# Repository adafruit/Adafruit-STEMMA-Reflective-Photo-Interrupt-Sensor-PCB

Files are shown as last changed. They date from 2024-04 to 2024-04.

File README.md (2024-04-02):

## Adafruit STEMMA Reflective Photo Interrupt Sensor - TCRT1000 PCB

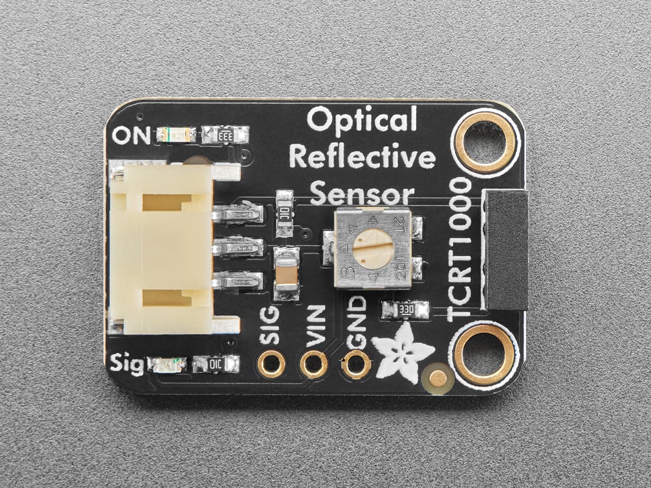
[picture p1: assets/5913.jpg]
<a href="http://www.adafruit.com/products/5913"><br/>
Click here to purchase one from the Adafruit shop</a>

PCB files for the Adafruit STEMMA Reflective Photo Interrupt Sensor - TCRT1000. 

Format is EagleCAD schematic and board layout
* https://www.adafruit.com/product/5913

### Description

An optical reflective sensor is a composite electronic device with two elements - an IR LED and an IR photo-transistor. The IR LED blasts light, and when something bounces the light back to the photo-transistor, the transistor turns on and the amount of current flowing through it increases. This makes the sensor great at detecting when something is in front of the sensor: when nothing is there the IR light never gets reflected back and the transistor stays off.

We have two versions of this sensor that are 'breadboard' friendly, the ITR20001 and a chunky all-in-one Infrared Reflective Sensor, but both are tough to mount, and require wiring up with resistors to get working. To make usage super fast and no-soldering-or-breadboarding-required, the Adafruit STEMMA Reflective Photo Interrupt Sensor is ready to go out of the box.

Power it with 3 to 5V DC and read the signal off the output pin to quickly detect reflective surfaces. A green LED tells you that the board is powered,  and a red LED will light up to let you know when the phototransistor is activated. (Both LEDs can be disabled)

Onboard we have a TCRT1000 right-angle sensor module. A potentiometer allows adjustment of how bright the IR emitter is, turn it all the way down for about 1mA, turn it all the way up for about 100mA. Then the receiving phototransistor is biased with a 10K pullup. When no IR light is detected, the output signal pin is high. When IR is bounced back, the voltage will drop down towards 0V.

This board has a simple plug-and-play JST PH (2mm pitch) input connector for solderless use. For use with a CircuitPlayground or micro:bit, this JST to alligator-clip cable works best. Red is power, ground is black and signal is white. For use with a breadboard, try this JST to male/plug-header. (We also have a socket-header cable if you want)

### License

Adafruit invests time and resources providing this open source design, please support Adafruit and open-source hardware by purchasing products from [Adafruit](https://www.adafruit.com)!

Designed by Limor Fried/Ladyada for Adafruit Industries.

Creative Commons Attribution/Share-Alike, all text above must be included in any redistribution. 
See license.txt for additional details.

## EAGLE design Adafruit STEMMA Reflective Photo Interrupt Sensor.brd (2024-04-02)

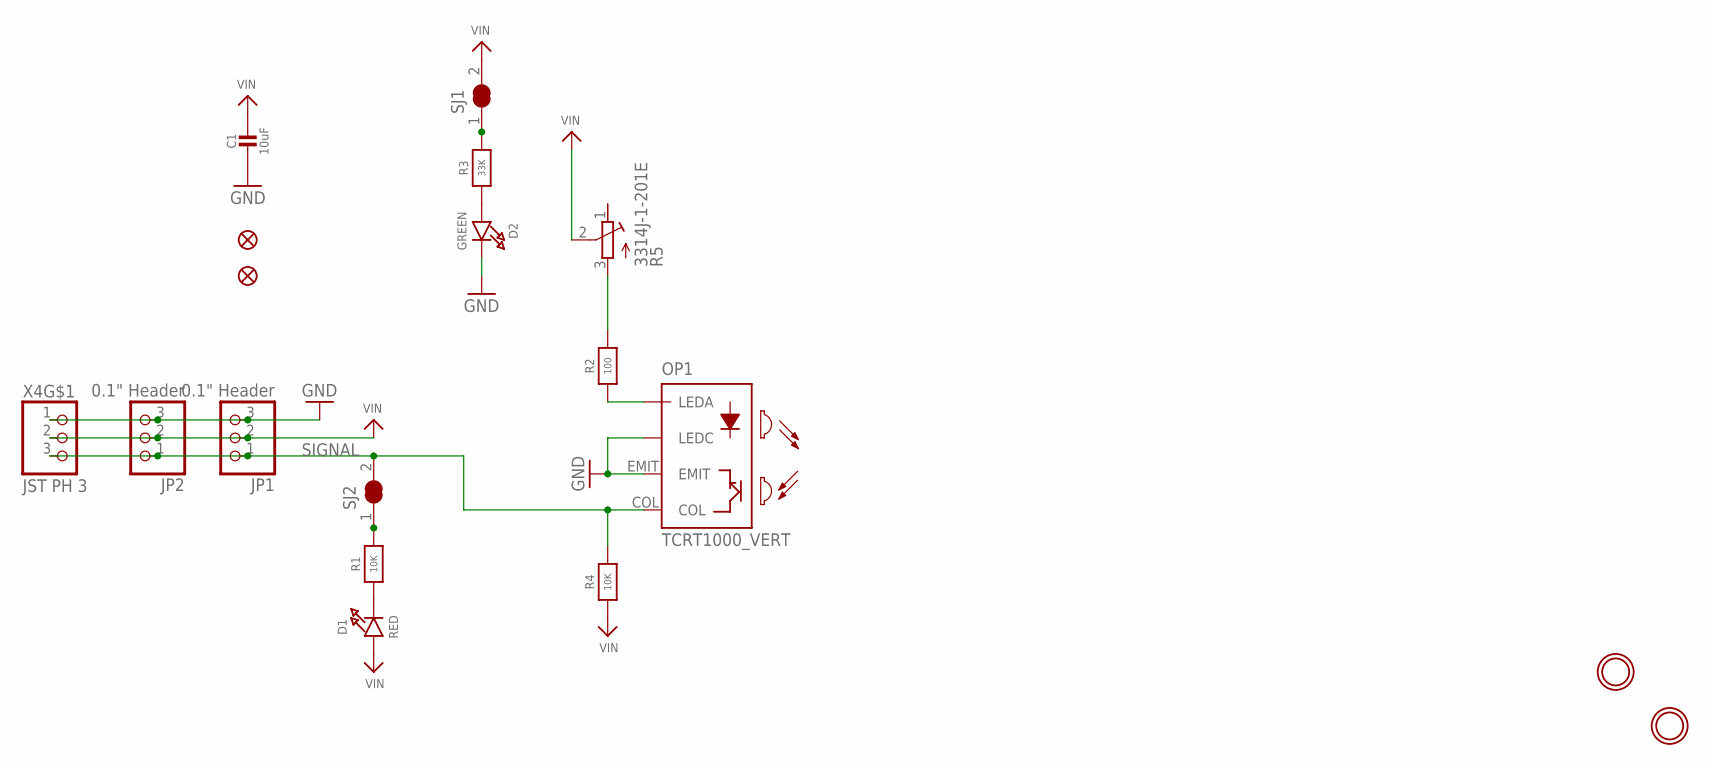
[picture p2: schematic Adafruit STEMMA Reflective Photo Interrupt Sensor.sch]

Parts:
C1: 10uF; 0805-NO
D1: RED; CHIPLED_0603_NOOUTLINE
D2: GREEN; CHIPLED_0603_NOOUTLINE
FID2, FID3: FIDUCIAL_1MM
JP1: 0.1" Header; 1X03_OVAL
JP2: 0.1" Header; 1X03_ROUND
OP1: TCRT1000_VERT; TCRT1000
R1, R4: 10K; 0603-NO
R2: 100; 0603-NO
R3: 33K; 0603-NO
R5: 3314J-1-201E; RTRIM3314J
SJ1, SJ2: SOLDERJUMPER_CLOSED; SOLDERJUMPER_CLOSEDWIRE
U$1, U$8: MOUNTINGHOLE2.5; MOUNTINGHOLE_2.5_PLATED
X4: JST PH 3; JSTPH3

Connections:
GND: C1.2, D2.C, JP1.3, JP2.3, OP1.EMIT, OP1.LEDC, X4.1
unnamed: R3.2, SJ1.1
unnamed: D1.C, R1.1
unnamed: R1.2, SJ2.1
unnamed: R2.2, R5.3 (A)
unnamed: OP1.LEDA, R2.1
unnamed: D2.A, R3.1
SIGNAL: JP1.1, JP2.1, OP1.COL, R4.2, SJ2.2, X4.3
VIN: C1.1, D1.A, JP1.2, JP2.2, R4.1, R5.2 (S), SJ1.2, X4.2

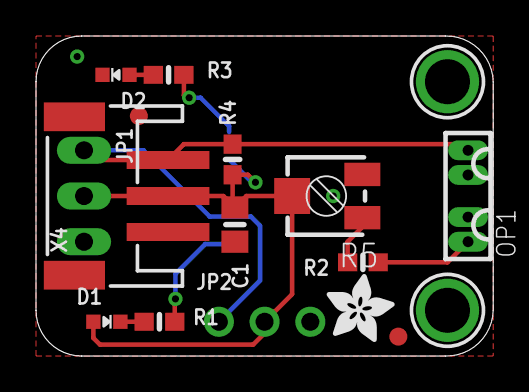
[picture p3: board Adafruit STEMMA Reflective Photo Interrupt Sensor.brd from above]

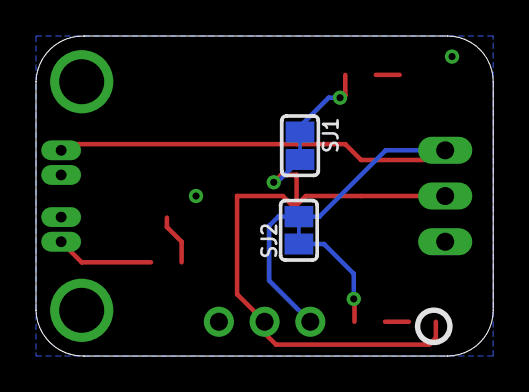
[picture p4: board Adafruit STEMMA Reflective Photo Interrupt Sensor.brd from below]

Board: 2 copper layers, 25.4 x 17.8 mm, 36 parts (12 on the bottom side), 9 nets.

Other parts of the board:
PLABEL0: PLABEL0
PLABEL1: PLABEL1
PLABEL7: PLABEL7
PLABEL8: PLABEL8
PLABEL9: PLABEL9
PLABEL10: PLABEL10
PLABEL11: PLABEL11
PLABEL12: PLABEL12
PLABEL13: PLABEL13
PLABEL14: PLABEL14
PLABEL15: PLABEL15
PLABEL16: PLABEL16
PLABEL17: PLABEL17
PLABEL18: PLABEL18
PLABEL19: PLABEL19
PLABEL20: PLABEL20
U$5: PCBFEAT-REV-040
U$10: ADAFRUIT_3.5MM

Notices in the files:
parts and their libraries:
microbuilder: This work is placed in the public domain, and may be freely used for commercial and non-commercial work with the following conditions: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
